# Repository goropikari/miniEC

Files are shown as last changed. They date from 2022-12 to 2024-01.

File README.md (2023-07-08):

# 小石 (miniEC)

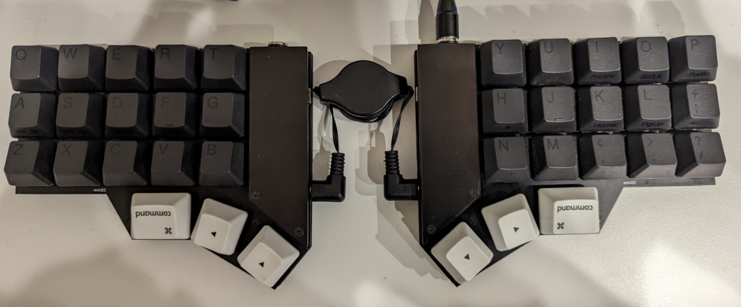
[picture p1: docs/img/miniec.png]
miniec


小石(miniEC) is a electrocapacitive split keyboard inspired by Manta40([KamoNanban](https://github.com/KamoNanban)), CorneEC([sekigon-gonnoc](https://github.com/sekigon-gonnoc)) and EC Helix([ginjake](https://github.com/ginjake)).

ビルドガイド
- [prototype, ~v1](https://github.com/goropikari/miniEC/blob/prototype/README.md)
- [v1~](https://github.com/goropikari/miniEC/blob/v1/docs/build_guide.md)

[販売ページ](https://pikarikbd.booth.pm/items/4799710)

License
- keyboards/miniec/, build/, docker_build.sh: GNU General Public License v3.0
- 3d_model/, plate/: [Creative Commons Attribution 4.0 International License](https://creativecommons.org/licenses/by/4.0/)

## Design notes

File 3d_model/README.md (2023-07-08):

小石用の 3D モデルデータです。

- stand.stl: 組み立ての際にプランジャーを落とした状態にするための台です。組立後はメンテナンス時に使うと便利かもしれません。
- case-left.stl, case-right.stl: 小石用のケースです。ボトムプレートの代わりにお使いください。こちらのデータを使う場合は M4 スペーサーは使用しないでください。

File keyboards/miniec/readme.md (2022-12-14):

# miniec

miniec

*A short description of the keyboard/project*

* Keyboard Maintainer: [goropikari](https://github.com/goropikari)
* Hardware Supported: *The PCBs, controllers supported*
* Hardware Availability: *Links to where you can find this hardware*

Make example for this keyboard (after setting up your build environment):

    make miniec:default

Flashing example for this keyboard:

    make miniec:default:flash

See the [build environment setup](https://docs.qmk.fm/#/getting_started_build_tools) and the [make instructions](https://docs.qmk.fm/#/getting_started_make_guide) for more information. Brand new to QMK? Start with our [Complete Newbs Guide](https://docs.qmk.fm/#/newbs).

## Bootloader

Enter the bootloader in 3 ways:

* **Bootmagic reset**: Hold down the key at (0,0) in the matrix (usually the top left key or Escape) and plug in the keyboard
* **Physical reset button**: Briefly press the button on the back of the PCB - some may have pads you must short instead
* **Keycode in layout**: Press the key mapped to `QK_BOOT` if it is available

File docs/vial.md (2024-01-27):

vial 対応は試験的です。今後もサポートするかは未定です。
[vial 0.7.1](https://github.com/vial-kb/vial-gui/releases/tag/v0.7.1) で動作を確認しています。

## ローカルで flash する場合
```bash
git clone --depth 1 --recurse-submodules --shallow-submodules -b v1 https://github.com/goropikari/miniEC
cd miniEC
python3 -m pip install -r requirements-vial.txt
ln -s $(pwd)/keyboards/miniec vial-qmk/keyboards/miniec
cd vial-qmk
make miniec:vial:flash
```

## Docker を使用する場合
```bash
git clone --depth 1 -b v1 https://github.com/goropikari/miniEC
cd miniEC
QMK_VERSION=vial-qmk-20240126214337 ./docker_build.sh miniec:vial:flash
```

## QMK Toolbox を使用する場合
[build/miniec_vial.hex](../build/miniec_vial.hex) を [qmk toolbox](https://github.com/qmk/qmk_toolbox) 使用して flash することも出来ます。

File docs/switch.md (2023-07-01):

# 動作確認済みスイッチ

一般的なメカニカルスイッチと異なり静電容量無接点方式スイッチは構成パーツが別々で販売されております。
基本的なパーツはハウジング、プランジャー、コニカルスプリング、ラバーシートの4点から構成されます。
ハウジングとプランジャーは適合する組み合わせでないといけませんが、コニカルスプリング・ラバーシートはどれを選んでも問題ないように思えます(全ての組み合わせを試したわけではないので保証はしません)。

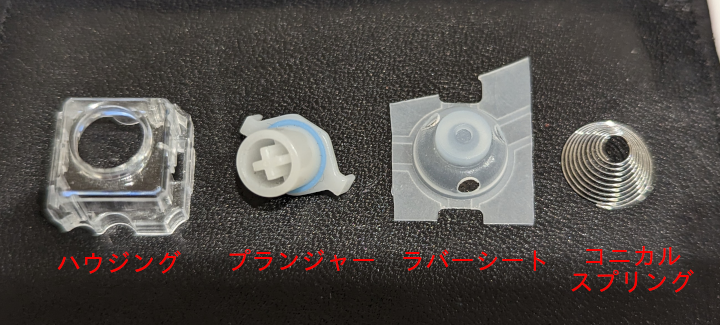
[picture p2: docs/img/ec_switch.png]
ec switch


ここでは実際に動作することが確認できた組み合わせ例を紹介します。
なお便宜上、NIZ スイッチや BTO スイッチなどと書いていますがハウジングがそのメーカーのものというだけで全てのパーツのメーカーを揃えているわけではないので注意してください。静電容量無接点方式スイッチの場合、メカニカルスイッチでいうところのキメラスイッチは珍しくありません。

## NIZ スイッチ

NIZ はハウジング、プランジャー、ラバーシートは販売していますがコニカルスプリングは単独で販売していないため他のメーカー製のものを組み合わせる必要があります。またラバーシートは日本国内のショップでは取り扱いがないため NIZ 本家のサイトから購入し輸入する必要があります。

私が実際に試した構成は以下のようなものです。(全て遊舎工房で購入。2023/6/17 現在は全て在庫切れとなっており長らく在庫切れの状態が続いているため今後取り扱いはされないかもしれません。)
- [NEW NIZ EC SWITCH](https://shop.yushakobo.jp/products/5224?variant=44218541080807)
  - ハウジング・プランジャーのセットです
- [静電容量式キーボード用円錐バネ （30個）](https://shop.yushakobo.jp/products/4679?variant=43877011095783)
  - コニカルスプリング
- [静電容量ラバーシート](https://shop.yushakobo.jp/products/a0500er-01-1?variant=37665368080545)
  - ラバーシート

私は実際には購入していませんが beekeeb でセットで購入できるようです。<br>
https://shop.beekeeb.com/product/niz-ec-switch/

## BTO(Bit Trade One) スイッチ

- [ADELCPS 静電容量スイッチ4点セット10組 ](https://btoshop.jp/products/adelcps?_pos=1&_sid=e6a17b2ee&_ss=r)
  - ハウジング、プランジャー、コニカルスプリングのセットです
- [静電容量ラバーシート](https://btoshop.jp/products/adelcpru?_pos=1&_sid=45ca45893&_ss=r)
  - ラバーシート

## 東プレスイッチ

東プレスイッチは個別で販売していないため Realforce を分解してパーツ取りします。
全てのモデルで分解できるのかわかりませんが、[Realforce 108UBK SJ08B0](https://www.realforce.co.jp/products/discontinued/108UBK_SJ08B0/) が分解できることは確認しています。

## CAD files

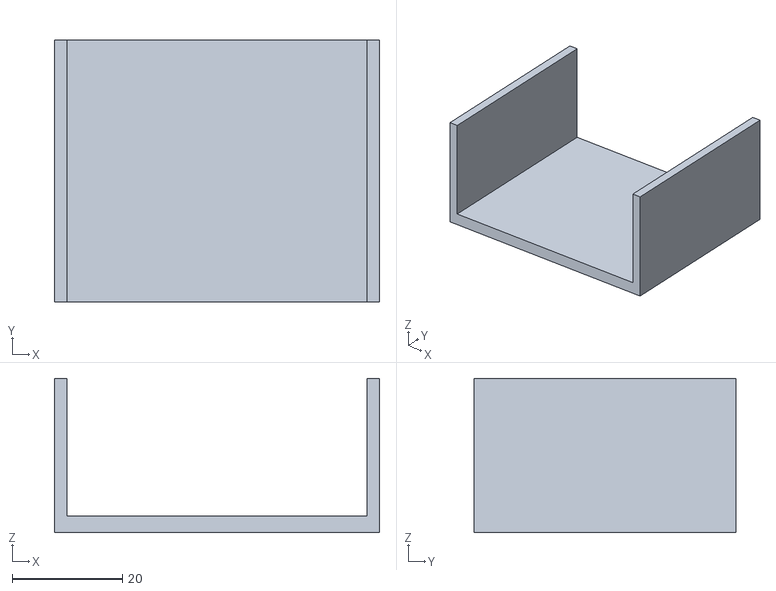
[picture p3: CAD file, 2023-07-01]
3d_model/stand.stl
59.0 x 47.6 x 28.0

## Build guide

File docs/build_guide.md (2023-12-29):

# 小石(miniEC) Build Guide

miniec

[販売ページ](https://pikarikbd.booth.pm/items/4799710)

- [小石(miniEC) Build Guide](#小石miniec-build-guide)
  - [部品](#部品)
    - [キット同封物](#キット同封物)
    - [その他必要なもの](#その他必要なもの)
  - [実装](#実装)
    - [表裏](#表裏)
    - [ProMicro・TRRS ジャック・タクトスイッチのハンダ付け](#promicrotrrs-ジャックタクトスイッチのハンダ付け)
    - [スイッチ](#スイッチ)
      - [NIZ のスイッチの場合](#niz-のスイッチの場合)
      - [BTO のスイッチの場合](#bto-のスイッチの場合)
      - [東プレスイッチ(Realforce) の場合](#東プレスイッチrealforce-の場合)
      - [すべてのスイッチ共通](#すべてのスイッチ共通)
    - [ProMicro カバー](#promicro-カバー)
    - [メイン基板・ボトムプレート・ゴム足](#メイン基板ボトムプレートゴム足)
  - [Firmware 焼き](#firmware-焼き)
    - [QMK Firmware 環境構築](#qmk-firmware-環境構築)
      - [ローカル環境に構築](#ローカル環境に構築)
      - [Docker を使う場合](#docker-を使う場合)
      - [vial を使う場合(試験的)](#vial-を使う場合試験的)
    - [入力テスト用キーマップ](#入力テスト用キーマップ)
    - [閾値を調整する](#閾値を調整する)
    - [トラブルシューティング](#トラブルシューティング)
  - [オプション](#オプション)
    - [ケース](#ケース)
    - [プレートデータ](#プレートデータ)

## 部品
### キット同封物

| 名前 | 数量 |
|---|---|
| メインPCB | 2 |
| トッププレート | 2 |
| ボトムプレート | 2 |
| マイコンカバー | 2 |
| TRRS ジャック  ※ | 2 |
| タクトスイッチ ※ | 2 |
| M2, 8 mm スペーサー | 14 |
| M2, 5 mm ねじ | 28 |
| M4, 2 mm スペーサー | 10 |
| ゴム足 | 8 |

※ はんだ付け済みの場合は同封されていません。

### その他必要なもの

| 名前 | 数量 | 備考 |
|---|---|---|
| ProMicro | 2 | 動作確認済みは以下です<br>- https://shop.yushakobo.jp/products/pro-micro<br>- https://talpkeyboard.net/items/62e24e6f8a0bd07fe2d38137 |
| 2.5~3.5 mm 12pin ピンヘッダー or コンスルー | 4 | ピンヘッダーであれば ProMicro を購入するとおそらく同封されています。コンスルーは遊舎工房や TALP KEYBOARD から購入できます。<br>- https://shop.yushakobo.jp/products/31 <br>- https://talpkeyboard.net/items/5e056626d790db16e2889233 |
| スイッチ | 36キー分 | 使用できるスイッチに関しては「[動作確認済みスイッチ](switch.md)」をご参照ください |
| キーキャップ | 36キー分 | NIZ, BTO のスイッチだと CherryMX 用のものが使えます |
| TRRS or TRS ケーブル | 1 | - https://shop.yushakobo.jp/products/trrs_cable<br>- https://www.amazon.co.jp/gp/product/B08T5TT859/ |

## 実装

### 表裏

チップがすでにはんだ付けされている面が裏です。

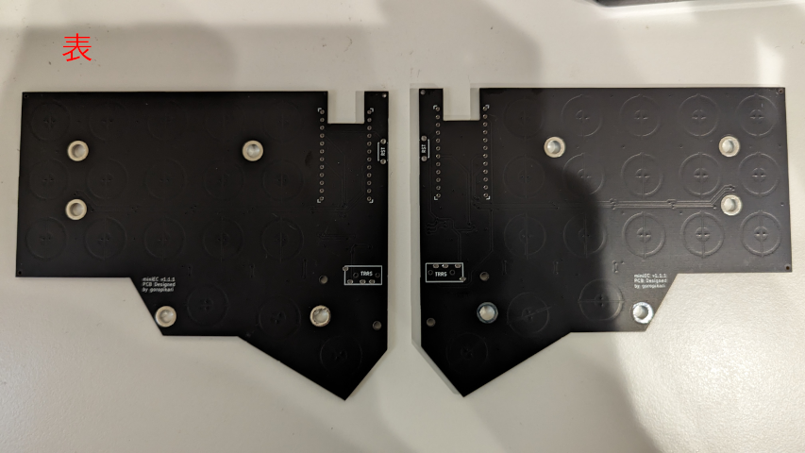
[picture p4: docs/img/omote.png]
表


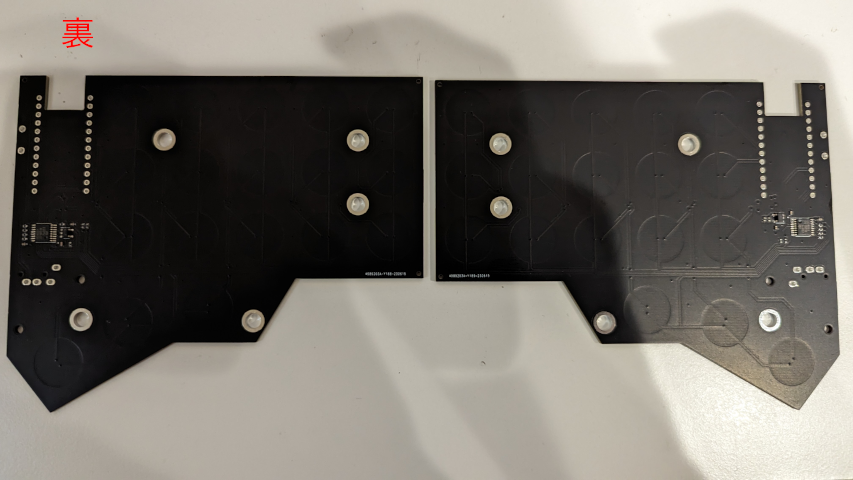
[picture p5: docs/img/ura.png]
裏


### ProMicro・TRRS ジャック・タクトスイッチのハンダ付け
写真のように ProMicro、TRRS ジャック、タクトスイッチ(リセットスイッチ)を配置しハンダ付けします。実装面をお間違えなきようお気をつけください。
最終的にチップが表面に出ないのが正しいです。

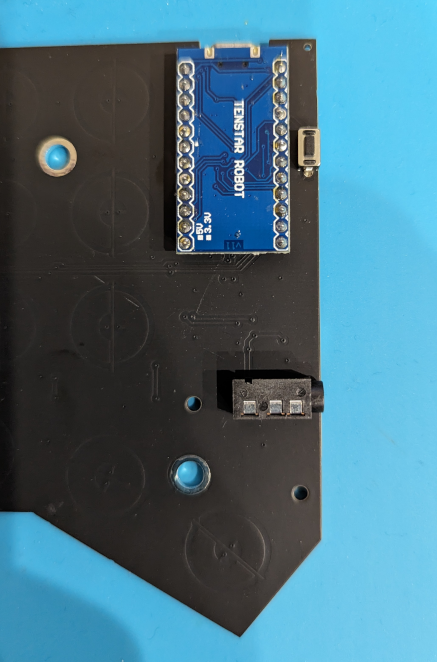
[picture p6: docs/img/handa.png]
はんだ付け


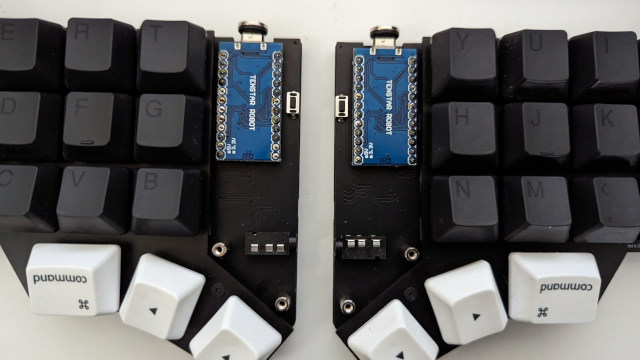
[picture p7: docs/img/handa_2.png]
はんだ付け 2


### スイッチ

トッププレートに M2, 8mm スペーサーをネジで固定します。

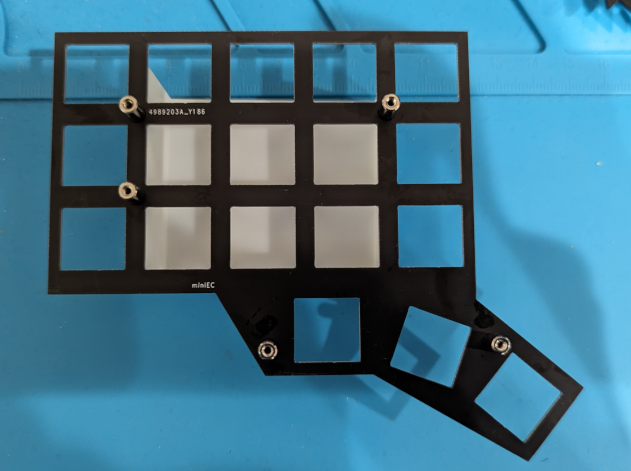
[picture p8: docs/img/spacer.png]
スペーサー


次にハウジングをトッププレートに嵌めていきます。(使用するハウジングに応じた記述に従ってください)

#### NIZ のスイッチの場合

ハウジングを下図のような向きにプレートに嵌めていきます。(NiZ のハウジングの場合はあまり向きにシビアではありませんが、中央にくるように配置してください。)

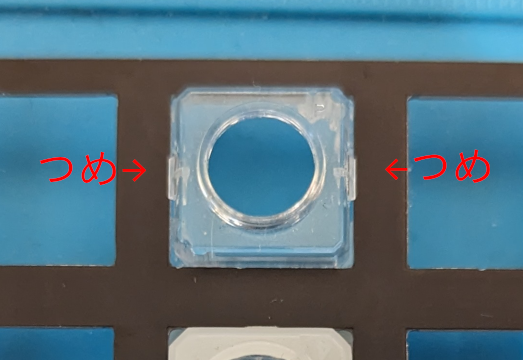
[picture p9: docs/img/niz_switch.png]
niz_switch


ハウジングを全て嵌めたらプランジャーをハウジングに入れていきます。プランジャーはハウジングのレールに沿うように入れてください。

正しい向き<br>
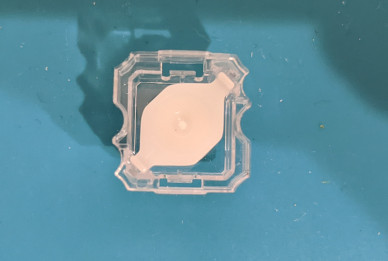
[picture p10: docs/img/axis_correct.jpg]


間違った向き<br>
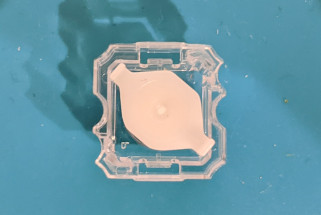
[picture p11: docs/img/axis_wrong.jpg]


トッププレートの穴の大きさの影響でプランジャーの滑りが悪くなることがあります。その場合は穴をヤスリで削って拡張してください。

#### BTO のスイッチの場合

プランジャーに O リングを通し、プランジャーを嵌めます。プランジャーはハウジングのレールに沿うように入れてください。

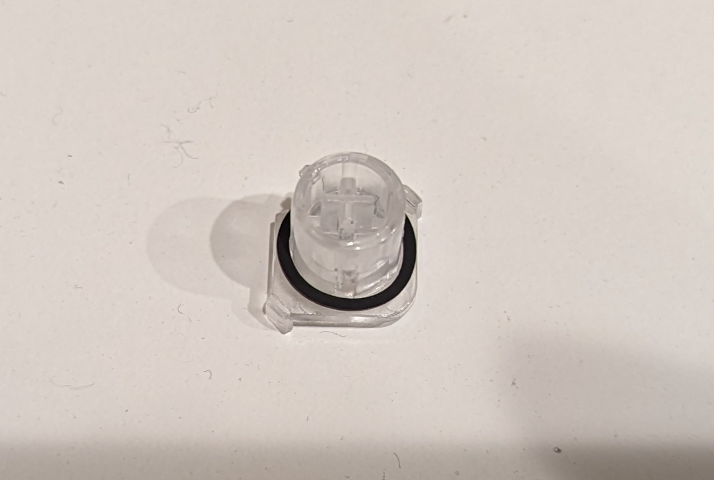
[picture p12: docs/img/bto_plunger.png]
プランジャー


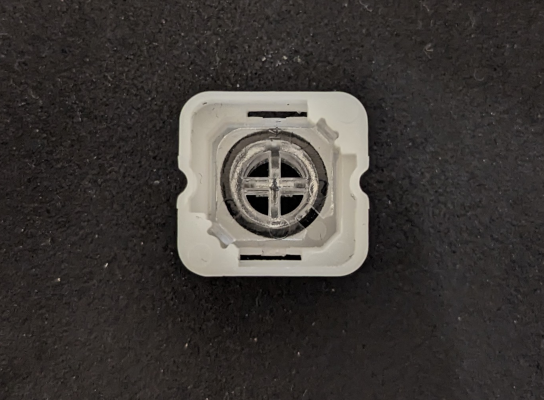
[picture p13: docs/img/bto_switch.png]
bto switch


ハウジングを下図のような向きにプレートに嵌めていきます。爪が引っかかる向きに注意してください。(穴のサイズ的に間違った向きにはそもそもハマりません)

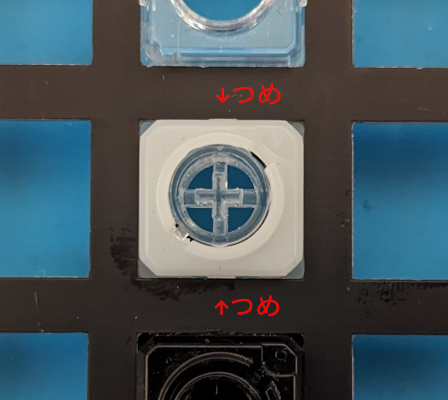
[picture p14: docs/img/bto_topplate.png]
bto switch plate


スペーサーが隅にある部分ではハウジングサイズが大きいためスペーサーと干渉します。その部分はハウジングの角をニッパーで切ったり、ヤスリで削ってください。(下の写真は東プレスイッチですが BTO のスイッチでも同様のことが起こります。)

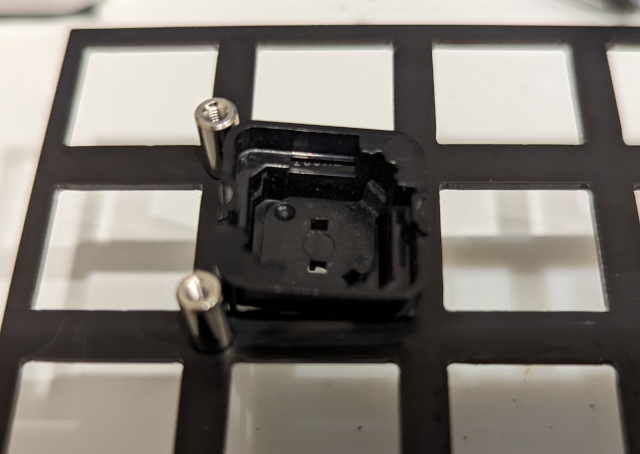
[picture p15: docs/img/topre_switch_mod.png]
topre switch


トッププレートの穴の大きさの影響でプランジャーの滑りが悪くなることがあります。その場合は穴をヤスリで削って拡張してください。

#### 東プレスイッチ(Realforce) の場合

Realforce を分解しハウジング等を入手します。
ハウジングを下図のような向きにプレートに嵌めていきます。爪が引っかかる向きに注意してください。(穴のサイズ的に間違った向きにはそもそもハマりません)

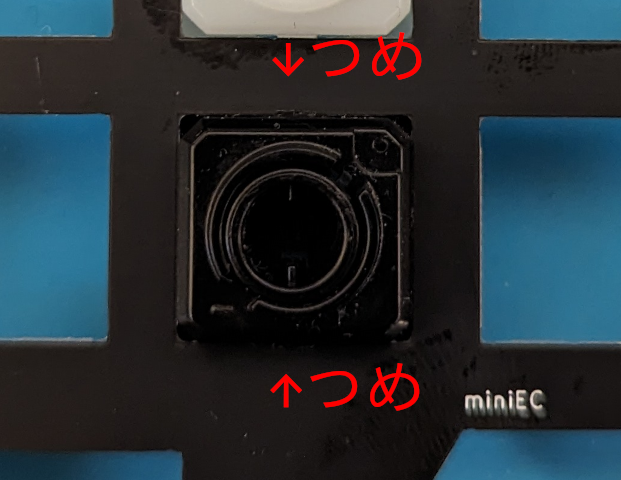
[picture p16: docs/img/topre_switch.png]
topre switch


スペーサーが隅にある部分ではハウジングサイズが大きいためスペーサーと干渉します。その部分はハウジングの角をニッパーで切ったり、ヤスリで削ってください。

topre switch

トッププレートの穴の大きさの影響でプランジャーの滑りが悪くなることがあります。その場合は穴をヤスリで削って拡張してください。

#### すべてのスイッチ共通

ラバーシートから5スイッチ分ずつ6行分と親指キー用を1スイッチ分ずつハサミで切り出します。
片手分の切り出し方の例として下の写真の赤線で囲った部分のように切り出すのがおすすめです。
全てを1スイッチ分ずつ切り分けたほうが後述する穴あけがやりやすいですが、コニカルスプリングがずれやすくなるのでまとめて切り出したほうが入力が安定します。

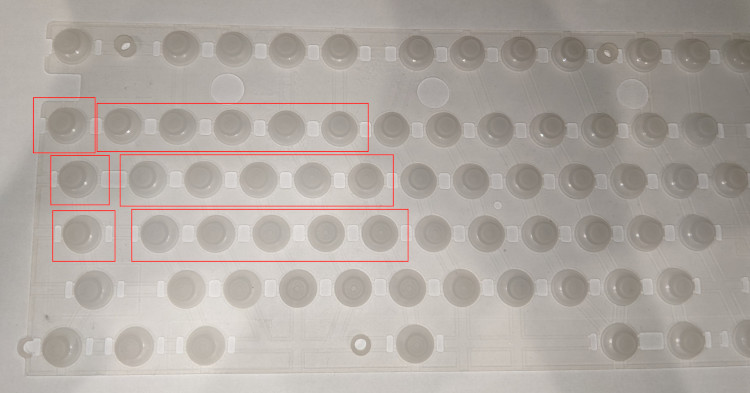
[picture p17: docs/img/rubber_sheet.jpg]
ラバーシート写真


(オプション) ラバーシートの側面に穴を開けると打鍵が軽くなります。一方でタクタイル感が減りリニアに違い打鍵感になります。

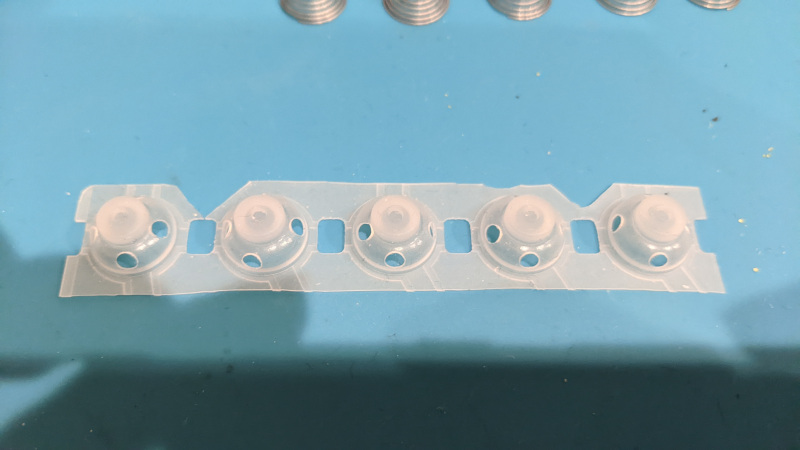
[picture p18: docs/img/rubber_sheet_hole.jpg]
穴を開けたラバーシート写真


切り出したラバーシートをスイッチに乗せ、コニカルスプリングを1つずつ配置します。コニカルスプリングは重なりやすいので1つずつになっていることを確認しながら配置してください。重なっていた場合入力がおかしくなることがあります。この時テーブルに直置きした状態で作業するとうまくハメられないため基板を浮かせた状態にしてください。
名刺やカードの短辺がおおよそ3キー分くらいの長さなのでプラスチック製のカードケースなどが使えると思います。
この作業のためだけの[スタンドの 3D モデルも用意](3d_model/stand.stl)しているため 3D プリンターを所有されている方は印刷して使用してみてください。

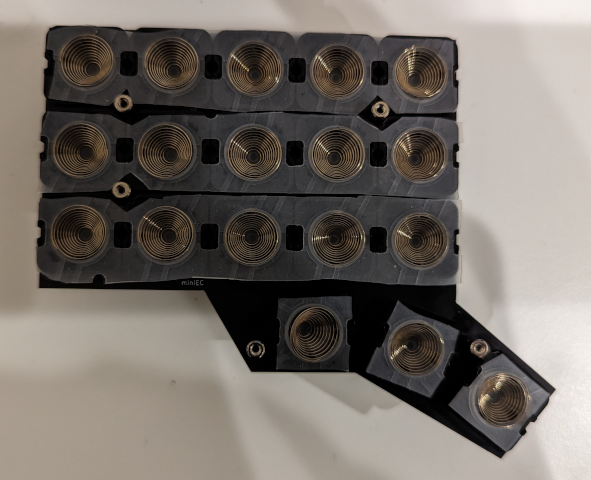
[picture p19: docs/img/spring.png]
spring


プランジャーが落ちきった状態で作業をする。

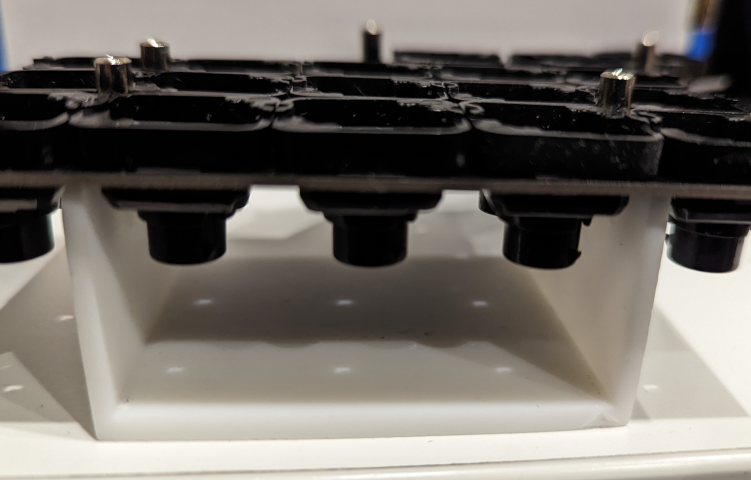
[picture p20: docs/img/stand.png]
stand


### ProMicro カバー

左右用のカバーが一つの基板として連結しているので切り離し、バリをヤスリで削ってください。

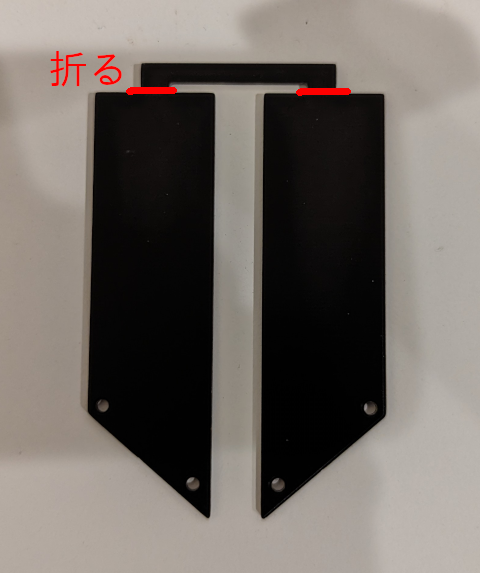
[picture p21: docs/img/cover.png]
promicro cover


PCB に M2 8 mm スペーサーを取り付け、カバーをネジで固定してください。

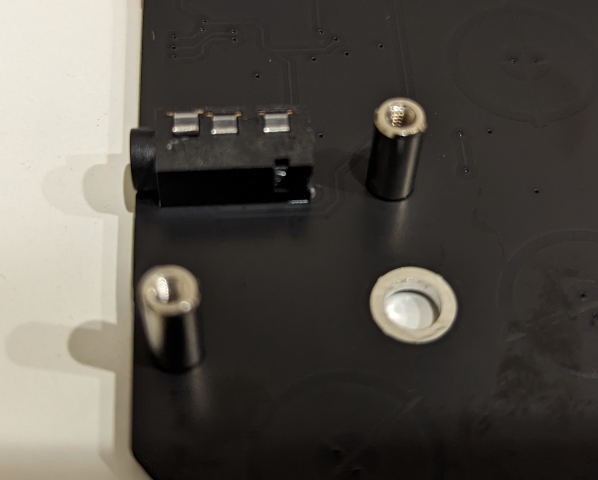
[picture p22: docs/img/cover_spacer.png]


### メイン基板・ボトムプレート・ゴム足

トッププレートにメイン基板を乗せ、スペーサーのところに M4 2 mm スペーサーをおいてください。
最後にボトムプレートをかぶせネジで止め、ゴム足を貼り付けてください。

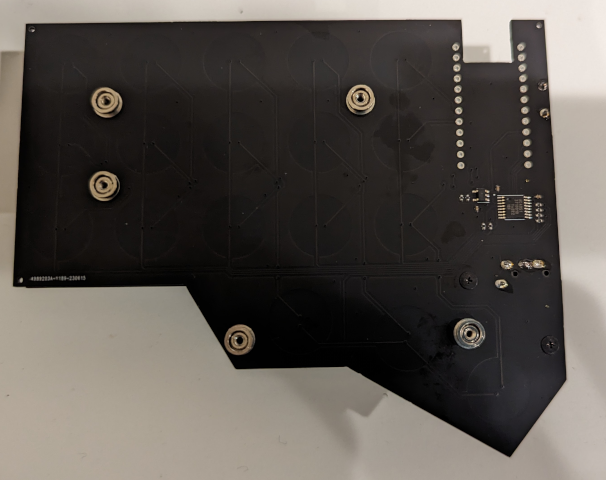
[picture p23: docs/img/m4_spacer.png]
m4 spacer


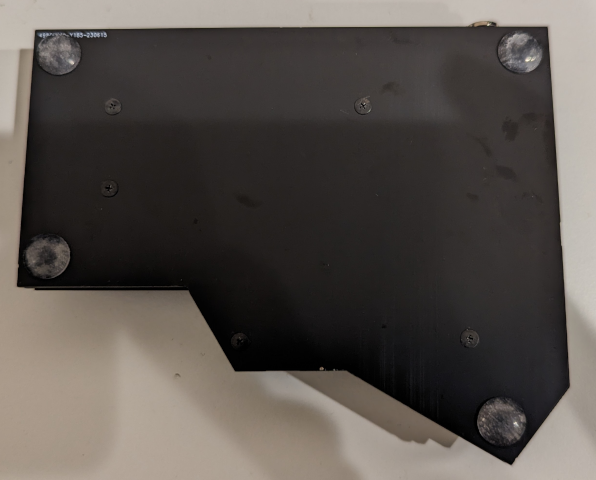
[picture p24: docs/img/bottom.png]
bottom plate


## Firmware 焼き

以降の動作確認は Linux(Ubuntu 22.04) で行っています。その他の OS をお使いの場合は適宜内容を読み替えてください。
Windows をお使いの場合は WSL で docker を使い firmware を build した後に生成された hex ファイルを qmk toolbox を使用して firmware を書き込むのが比較的楽だと思います。
QMK Firmware は version 0.23.2 を元にしています。公式サイトのドキュメンテーションとは version が異なることがあります。その場合は [version 0.23.2 の Doc](https://github.com/qmk/qmk_firmware/tree/0.23.2/docs) をご参照ください。

### QMK Firmware 環境構築
#### ローカル環境に構築

```bash
sudo apt-get update
sudo apt-get install -y git python3-pip make gcc-avr binutils-avr avr-libc avrdude vim gcc-arm-none-eabi ripgrep wget libc6-i386 libc6-dev-arm64-cross

git clone --depth 1 --recurse-submodules --shallow-submodules -b v1 https://github.com/goropikari/miniEC
cd miniEC
python3 -m venv env
source env/bin/activate
python3 -m pip install -r requirements.txt
ln -s $(pwd)/keyboards/miniec qmk_firmware/keyboards/miniec
cd qmk_firmware
```

#### Docker を使う場合

```bash
docker pull goropikari/qmkfm:0.23.2
git clone --depth 1 -b v1 https://github.com/goropikari/miniEC
cd miniEC
```

firmware を焼くときはこのリポジトリにある `keyboards` ディレクトリ以下を bind mount しています。閾値や keymap を変えるときはこのリポジトリ内のファイルを編集してください。
ビルドしてできた hex ファイルは `build` ディレクトリ以下に生成されます。

#### vial を使う場合(試験的)

vial 対応は試験的です。今後もサポートするかは未定です。
vial 0.7.1 で動作を確認しています。

[vial.md](vial.md) をご参照ください。

### 入力テスト用キーマップ

入力テスト用のキーマップを焼いて全キーが入力できるか確認してください

```bash
# ローカル環境を使う場合
make miniec:test:flash

# docker を使う場合
QMK_VERSION=0.23.2 ./docker_build.sh miniec:test:flash
```

`Waiting for USB serial port - reset your controller now (Ctrl+C to cancel)....` と出たら reset switch を2回押して firmware を書き込んでください。

※ `QMK_VERSION=0.23.2 ./docker_build.sh miniec:test` と `flash` を抜くとコンパイルするだけで終わります。WSL を使用している場合はこちらの方法が推奨です。

うまく入力ができなかった場合は後述の「[閾値を調整する](#閾値を調整する)」を参考にしきい値を調節してください。

入力がうまくできるようになったら `keyboards/miniec/keymaps/default/keymap.c` をお好みのキーマップに編集して firmware を焼き直し完成です。

```bash
# ローカル環境を使う場合
make miniec:default:flash

# docker を使う場合
QMK_VERSION=0.23.2 ./docker_build.sh miniec:default:flash
```

### 閾値を調整する

静電容量無接点方式スイッチではキーを押したときの静電容量の変化もとい電圧の変化を検出して押下判定をします。
`keyboards/miniec/config.h` にある `HIGH_THRESHOLD` に設定した値を超えるとキーが押された状態、`LOW_THRESHOLD` を下回るとキーが押されていない状態と判定されます。

[hid_listen](https://www.pjrc.com/teensy/hid_listen.html) を使うと各キーの電圧(スケールされている)を見ることが出来ます。公式ページからバイナリを落としてくるか下記のように docker で立ち上げ、キーボードを PC に繋いでください。[QMK Toolbox](https://github.com/qmk/qmk_toolbox#hid-console) でも同様の出力を得られるようですが確認できる環境を持ち合わせていないため未確認です。

```bash
docker run --rm -it --privileged -v /dev:/dev goropikari/hid_listen:1.01
```

下は2回分の読み取り値の例です(USB ケーブルが刺されている側だけの値が出力されます)。
キーを押していない状態が 70 以下、押した状態では 282 と他よりも高くなっています。
全キー分の値を見つつ最適な `HIGH_THRESHOLD`, `LOW_THRESHOLD` の値を決めてください

```
Waiting for device:
Listening:
  67  64  48  45  46  45
  18  37  45  34  30  63
  28  50  40  48  43  78

  64  68  47  41  41  32
  40  38  40  39  28  60
  27  52  39  46  43 282 <- 押したキー
```

キーを押したときに文字が入力されて邪魔な場合は何の文字も入力されない keymap を用意しているので一度そちらに firmware を焼き直してみてください。

```bash
# ローカル環境を使う場合
make miniec:blank:flash

# docker を使う場合
QMK_VERSION=0.23.2 ./docker_build.sh miniec:blank:flash
```

### トラブルシューティング

うまく機能しない場合に調査すべきポイントを [wiki](https://github.com/goropikari/miniEC/wiki/%E3%83%88%E3%83%A9%E3%83%96%E3%83%AB%E3%82%B7%E3%83%A5%E3%83%BC%E3%83%86%E3%82%A3%E3%83%B3%E3%82%B0) にまとめています。

## オプション

### ケース
小石用ケースの 3D モデルを配布しております。[左用](../3d_model/case-left.stl), [右用](../3d_model/case-right.stl)。

ご家庭の 3D プリンター、もしくは専門の業者に依頼して印刷してご使用ください。
こちらのケースはボトムプレートの代わりにご使用ください。その際、M4 2 mm スペーサーは使わないでください。

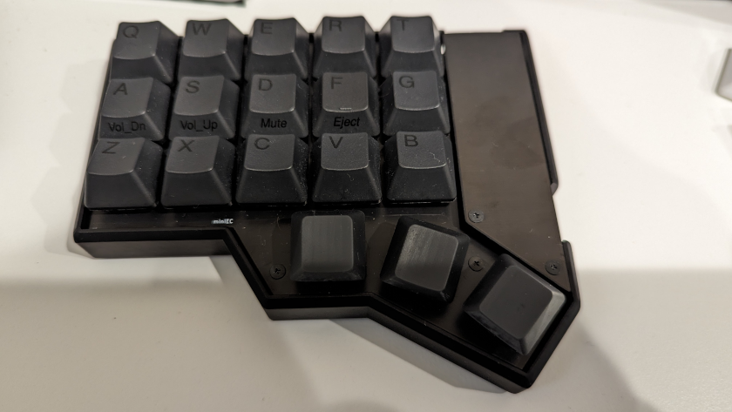
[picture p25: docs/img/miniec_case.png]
miniec case


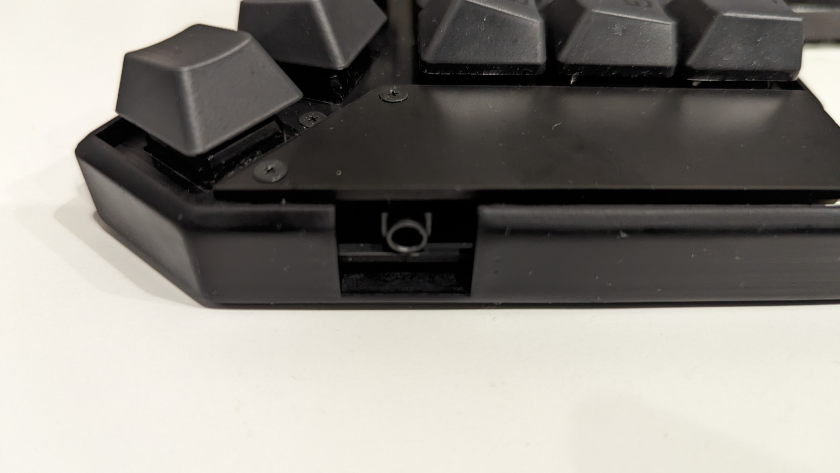
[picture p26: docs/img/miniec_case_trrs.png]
miniec case trrs hole


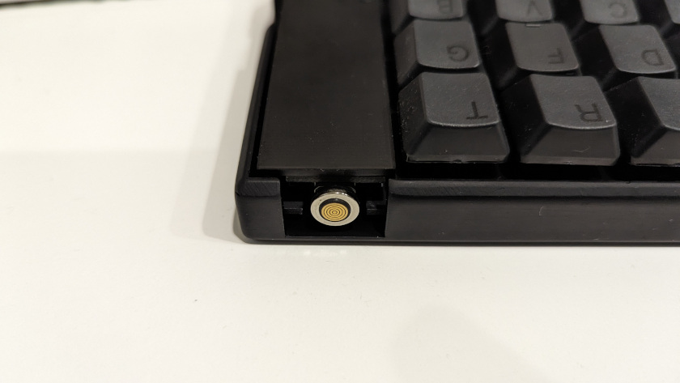
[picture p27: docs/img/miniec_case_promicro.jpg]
miniec case promicro hole


写真のケースは JLCPCB Resin Imagine Black で作りました。

### プレートデータ
ご自身でケースを作成されたい方は[ボトムプレートのデータ](../plate/)を KiCad, svg 形式で配布しておりますのでご活用ください。

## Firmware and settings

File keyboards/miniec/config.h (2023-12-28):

/*
Copyright 2020 sekigon-gonnoc
Copyright 2023 goropikari (@goropikari)

This program is free software: you can redistribute it and/or modify
it under the terms of the GNU General Public License as published by
the Free Software Foundation, either version 2 of the License, or
(at your option) any later version.
This program is distributed in the hope that it will be useful,
but WITHOUT ANY WARRANTY; without even the implied warranty of
MERCHANTABILITY or FITNESS FOR A PARTICULAR PURPOSE.  See the
GNU General Public License for more details.
You should have received a copy of the GNU General Public License
along with this program.  If not, see <http://www.gnu.org/licenses/>.
*/

#pragma once

// #define SELECT_SOFT_SERIAL_SPEED 3
// #define SERIAL_DEBUG
/*
 * Feature disable options
 *  These options are also useful to firmware size reduction.
 */

/* disable debug print */
//#define NO_DEBUG

/* disable print */
//#define NO_PRINT

/* disable action features */
//#define NO_ACTION_LAYER
//#define NO_ACTION_TAPPING
//#define NO_ACTION_ONESHOT
/* key matrix size */
#define MATRIX_ROWS 6
#define MATRIX_COLS 6

/* EC switch threshold with hysteresis */
// for v1.1.1
#define HIGH_THRESHOLD 130
#define LOW_THRESHOLD 120

#define TAP_CODE_DELAY 5
#define TAPPING_TERM 125
#define PERMISSIVE_HOLD

/*
 * Keyboard Matrix Assignments
 */
#define MATRIX_ROW_PINS { D4, C6, D7 }
#define COL_PINS { S1, S0, S3, S5, S7, S2 }
#define DISCHARGE_PIN B1
#define ANALOG_PORT F6
#define MUX_SEL_PINS { B6, B2, B3 }


/*
 * Split Keyboard specific options, make sure you have 'SPLIT_KEYBOARD = yes' in your rules.mk, and define SOFT_SERIAL_PIN.
 */
#define SOFT_SERIAL_PIN D2  // or D1, D2, D3, E6
#define SPLIT_HAND_PIN F4
// #define EE_HANDS
// #define MASTER_LEFT


/* Debounce reduces chatter (unintended double-presses) - set 0 if debouncing is not needed */
#define DEBOUNCE 5

/* define if matrix has ghost (lacks anti-ghosting diodes) */
//#define MATRIX_HAS_GHOST

/* Mechanical locking support. Use KC_LCAP, KC_LNUM or KC_LSCR instead in keymap */
#define LOCKING_SUPPORT_ENABLE
/* Locking resynchronize hack */
#define LOCKING_RESYNC_ENABLE

/* If defined, GRAVE_ESC will always act as ESC when CTRL is held.
 * This is useful for the Windows task manager shortcut (ctrl+shift+esc).
 */
//#define GRAVE_ESC_CTRL_OVERRIDE

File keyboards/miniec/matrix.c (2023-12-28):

/* Copyright 2020 sekigon-gonnoc
 * Copyright 2023 goropikari
 *
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
 * You should have received a copy of the GNU General Public License
 * along with this program.  If not, see <http://www.gnu.org/licenses/>.
 */

#include "quantum.h"
#include "ec_switch_matrix.h"
#include "matrix.h"
#include "debug.h"
#include "split_util.h"
#include "transport.h"
#include "debounce.h"

#define ERROR_DISCONNECT_COUNT 20

#define ROWS_PER_HAND (MATRIX_ROWS / 2)

/* matrix state(1:on, 0:off) */
extern matrix_row_t raw_matrix[MATRIX_ROWS];  // raw values
extern matrix_row_t matrix[MATRIX_ROWS];      // debounced values

// row offsets for each hand
uint8_t thisHand, thatHand;

// user-defined overridable functions
__attribute__((weak)) void matrix_slave_scan_user(void) {}

void matrix_init_custom(void) {
    // Turn off LED on ProMicro
    DDRD &= ~(1<<5);
    PORTD &= ~(1<<5);
    DDRB &= ~(1<<0);
    PORTB &= ~(1<<0);

    split_pre_init();

    ecsm_config_t ecsm_config;
    for (int r = 0; r < MATRIX_ROWS / 2; r++) {
        for (int c = 0; c < MATRIX_COLS; c++) {
            ecsm_config.low_threshold[r][c] = LOW_THRESHOLD;
            ecsm_config.high_threshold[r][c] = HIGH_THRESHOLD;
        }
    }
    if (isLeftHand) { // left side hand
        // specific configuration
    } else { // right side hand
        // キー毎に閾値を調整する例
        // uint16_t lows[MATRIX_ROWS / 2][MATRIX_COLS] = {
        //     { 0, 11, 10,  0,  0, 25},
        //     { 0, 15, 20, 15,  0,  0},
        //     { 0, 15, 25,  0,  0,  0},
        // };
        // uint16_t highs[MATRIX_ROWS / 2][MATRIX_COLS] = {
        //     { 0, 13, 15,  0,  0, 30},
        //     { 0, 20, 22, 20,  0,  0},
        //     { 0, 20, 30,  0,  0,  0},
        // };
        // for (int r = 0; r < MATRIX_ROWS / 2; r++) {
        //     for (int c = 0; c < MATRIX_COLS; c++) {
        //         if (lows[r][c] != 0) ecsm_config.low_threshold[r][c] = lows[r][c];
        //         if (highs[r][c] != 0) ecsm_config.high_threshold[r][c] = highs[r][c];
        //     }
        // }
    }

    ecsm_init(&ecsm_config);

    thisHand = isLeftHand ? 0 : (ROWS_PER_HAND);
    thatHand = ROWS_PER_HAND - thisHand;

    split_post_init();
}

bool matrix_scan_custom(matrix_row_t current_matrix[]) {
    bool updated = ecsm_matrix_scan(current_matrix);

#ifdef CONSOLE_ENABLE
    static int cnt = 0;
    if (cnt++ == 300) {
        cnt = 0;
        ecsm_print_matrix();
        print("\n");
    }
#endif

    return updated;
}

uint8_t matrix_scan(void) {
    bool changed = matrix_scan_custom(raw_matrix);

    debounce(raw_matrix, matrix + thisHand, ROWS_PER_HAND, changed);

    matrix_post_scan();
    return changed;
}

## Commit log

2023-07-01 add v1 build guide
    [plate_outline.kicad_pcb, plate_outline.kicad_sch, stand.stl]
2023-07-08 add description about case
2023-09-30 fix plate link
2023-09-30 update 同封物
2023-12-11 記述追加
2023-12-28 remove imperfect calibration
